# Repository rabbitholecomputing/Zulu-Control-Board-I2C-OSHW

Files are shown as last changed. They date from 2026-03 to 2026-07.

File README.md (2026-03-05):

# Zulu Control Board V1.1 I2C OSHW
This design was originally created to control the ZuluIDE in a 5.25" bracket. It has been relicensed under the OSHW CERN OWL-S V2 see [LICENSE](LICENSE) for the community to spin their own version or produce this design themselves.

The design is created in KiCAD 9.  Gerber, BOM, and position files can be built automatically as a Github action.

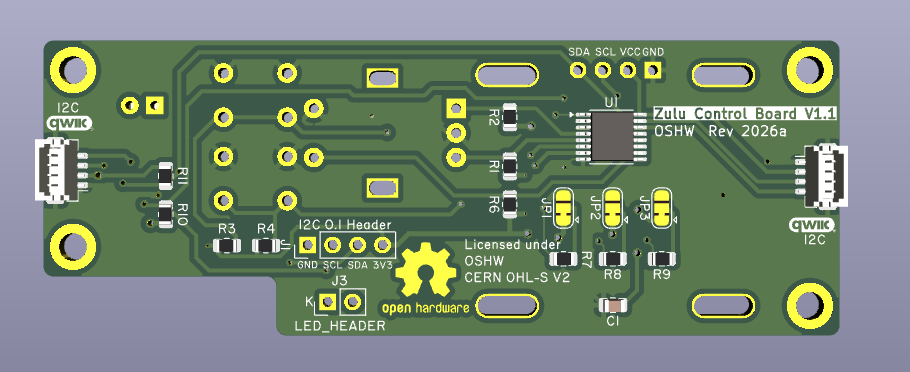
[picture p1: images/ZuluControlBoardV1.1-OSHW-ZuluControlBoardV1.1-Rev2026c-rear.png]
Zulu Control Board front render


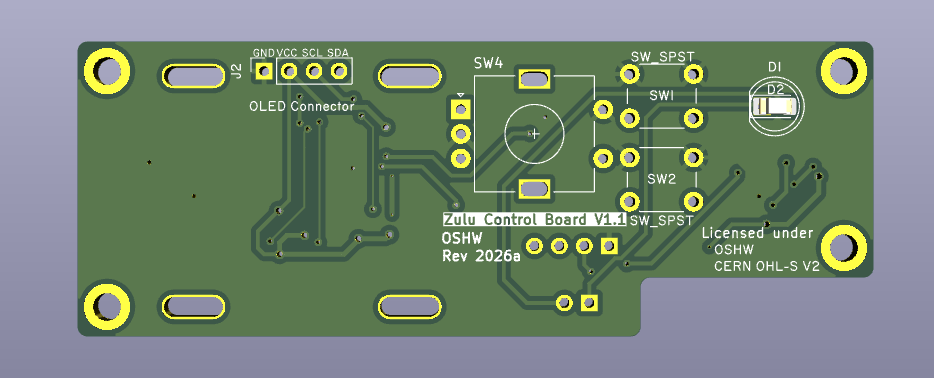
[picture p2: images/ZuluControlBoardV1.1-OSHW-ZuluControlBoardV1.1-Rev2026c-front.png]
Zulu Control Board front render


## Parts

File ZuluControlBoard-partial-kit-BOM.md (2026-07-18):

# i2c Zulu Control board BOM for partially-assembled PCB kit
## (all surface-mount components mounted)

* SW1 & SW2 - P/N MJTP1230BL Any 6x6mm footprint pushbutton tactile switch/pushbuttons should work.
*  J2 - [0.96" OLED module](https://www.digikey.com/en/products/detail/canaduino/26095/16822116), sourceable via Amazon, AliExpres, eBay, etc.
The 0.96" OLED display modules are commodity items, see https://www.amazon.com/dp/B09T6SJBV5. Any 128x64 SSD1306-based OLED display with the correct pinout (GND, VCC, SCL, SCA, _in that order_) should work.

* D1 - This 5mm activity LED is optional. If you choose to install an LED there, make sure it's intended to operate at ~3-3.3 volts DC.
 
* J2 - Optional two-pin LED activity header on the control board, which must be separately connected to the two-pin activity LED header on the ZuluSCSI, as the Qwiic cable does not carry signals for that. 

* SW4, Rotary encoder: Apls Alpine [EC11E152440D](https://tech.alpsalpine.com/e/products/category/encorders/sub/01/series/ec11e/) or [similar Chinese-made "**EC11E**" equivalent](https://www.amazon.com/s?k=rotary+encoder+EC11).

Please note that **non-pushbutton** rotary encoders **are not supported** by the firmware, so be sure to obtain one that has pushbutton/push-on support.

The following Alps Alpine EC11E rotary encoders are pushbutton-equipped models:

* [EC11E15244G1](https://octopart.com/search?specs=0&full_query=EC11E15244G1)
* [EC11E18244AU](https://octopart.com/search?specs=0&full_query=EC11E18244AU)
* [EC11E09244AQ](https://octopart.com/search?specs=0&full_query=EC11E09244AQ)
* [EC11E15244B2](https://octopart.com/search?specs=0&full_query=EC11E15244B2)
* [EC11E18244A5](https://octopart.com/search?specs=0&full_query=EC11E18244A5)

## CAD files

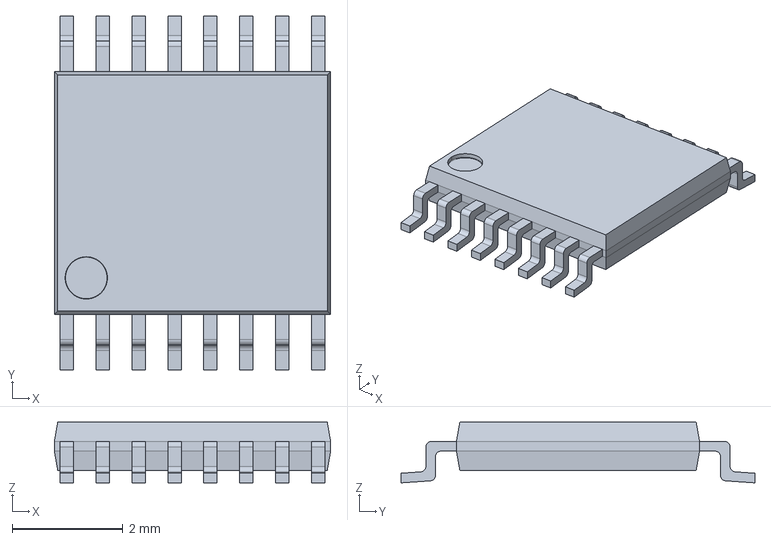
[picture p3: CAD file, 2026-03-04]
PCA9554APW_118/PCA9554APW_118.step
5.00 x 6.41 x 1.10 mm

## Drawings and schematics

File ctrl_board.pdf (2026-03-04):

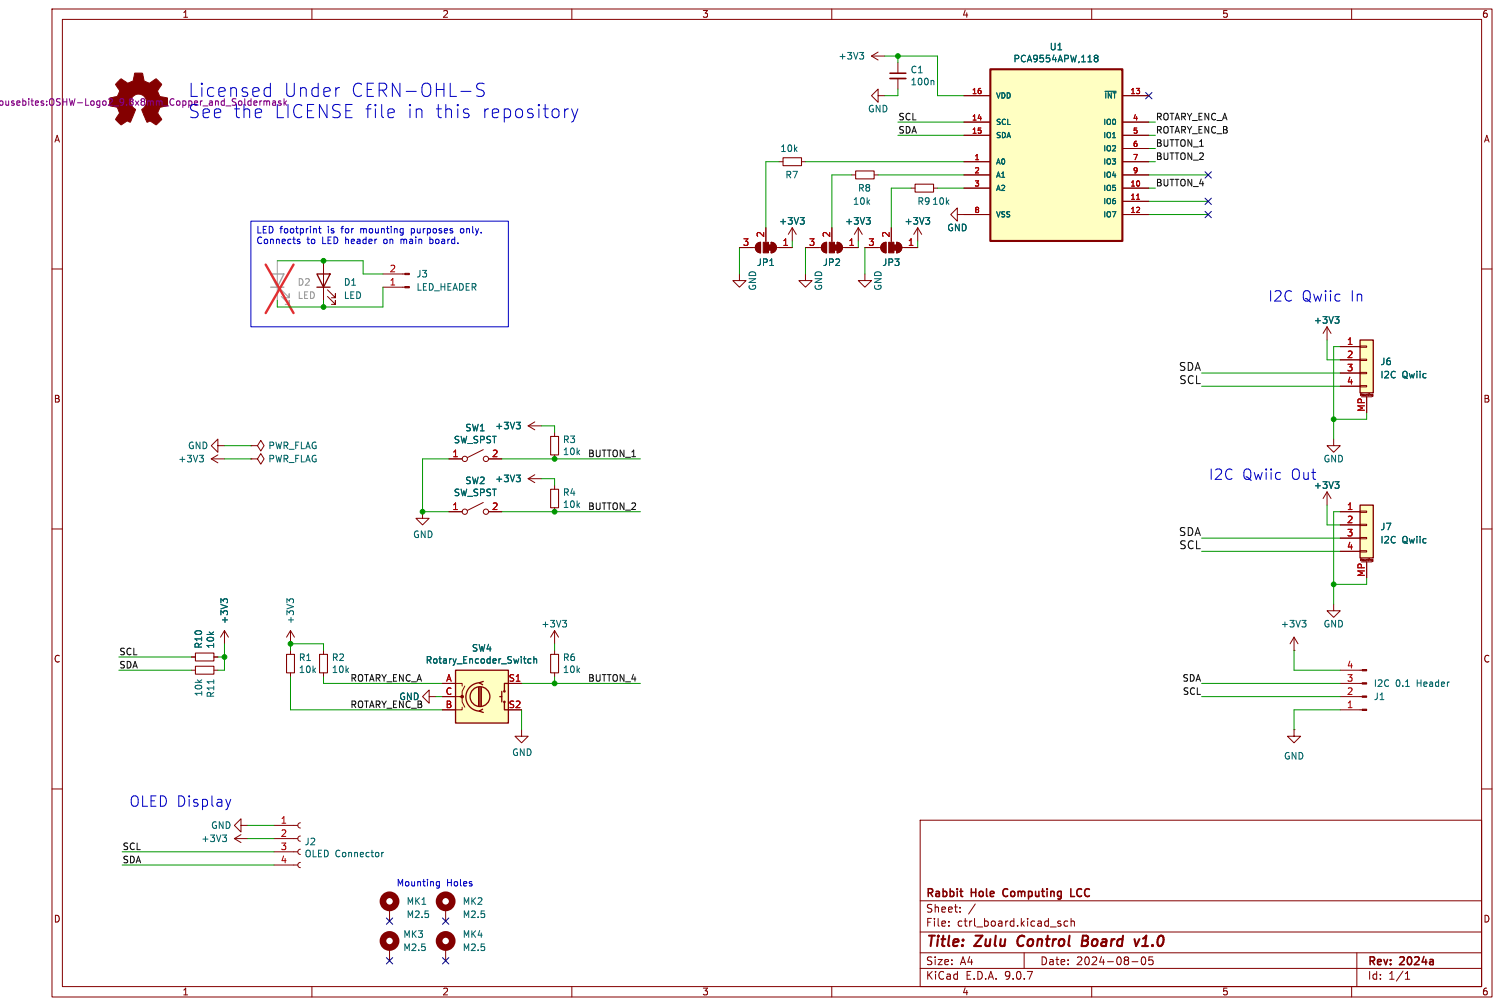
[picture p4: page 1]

See the LICENSE file in this repository

Id: 1/1 Title: Zulu Control Board v1.0

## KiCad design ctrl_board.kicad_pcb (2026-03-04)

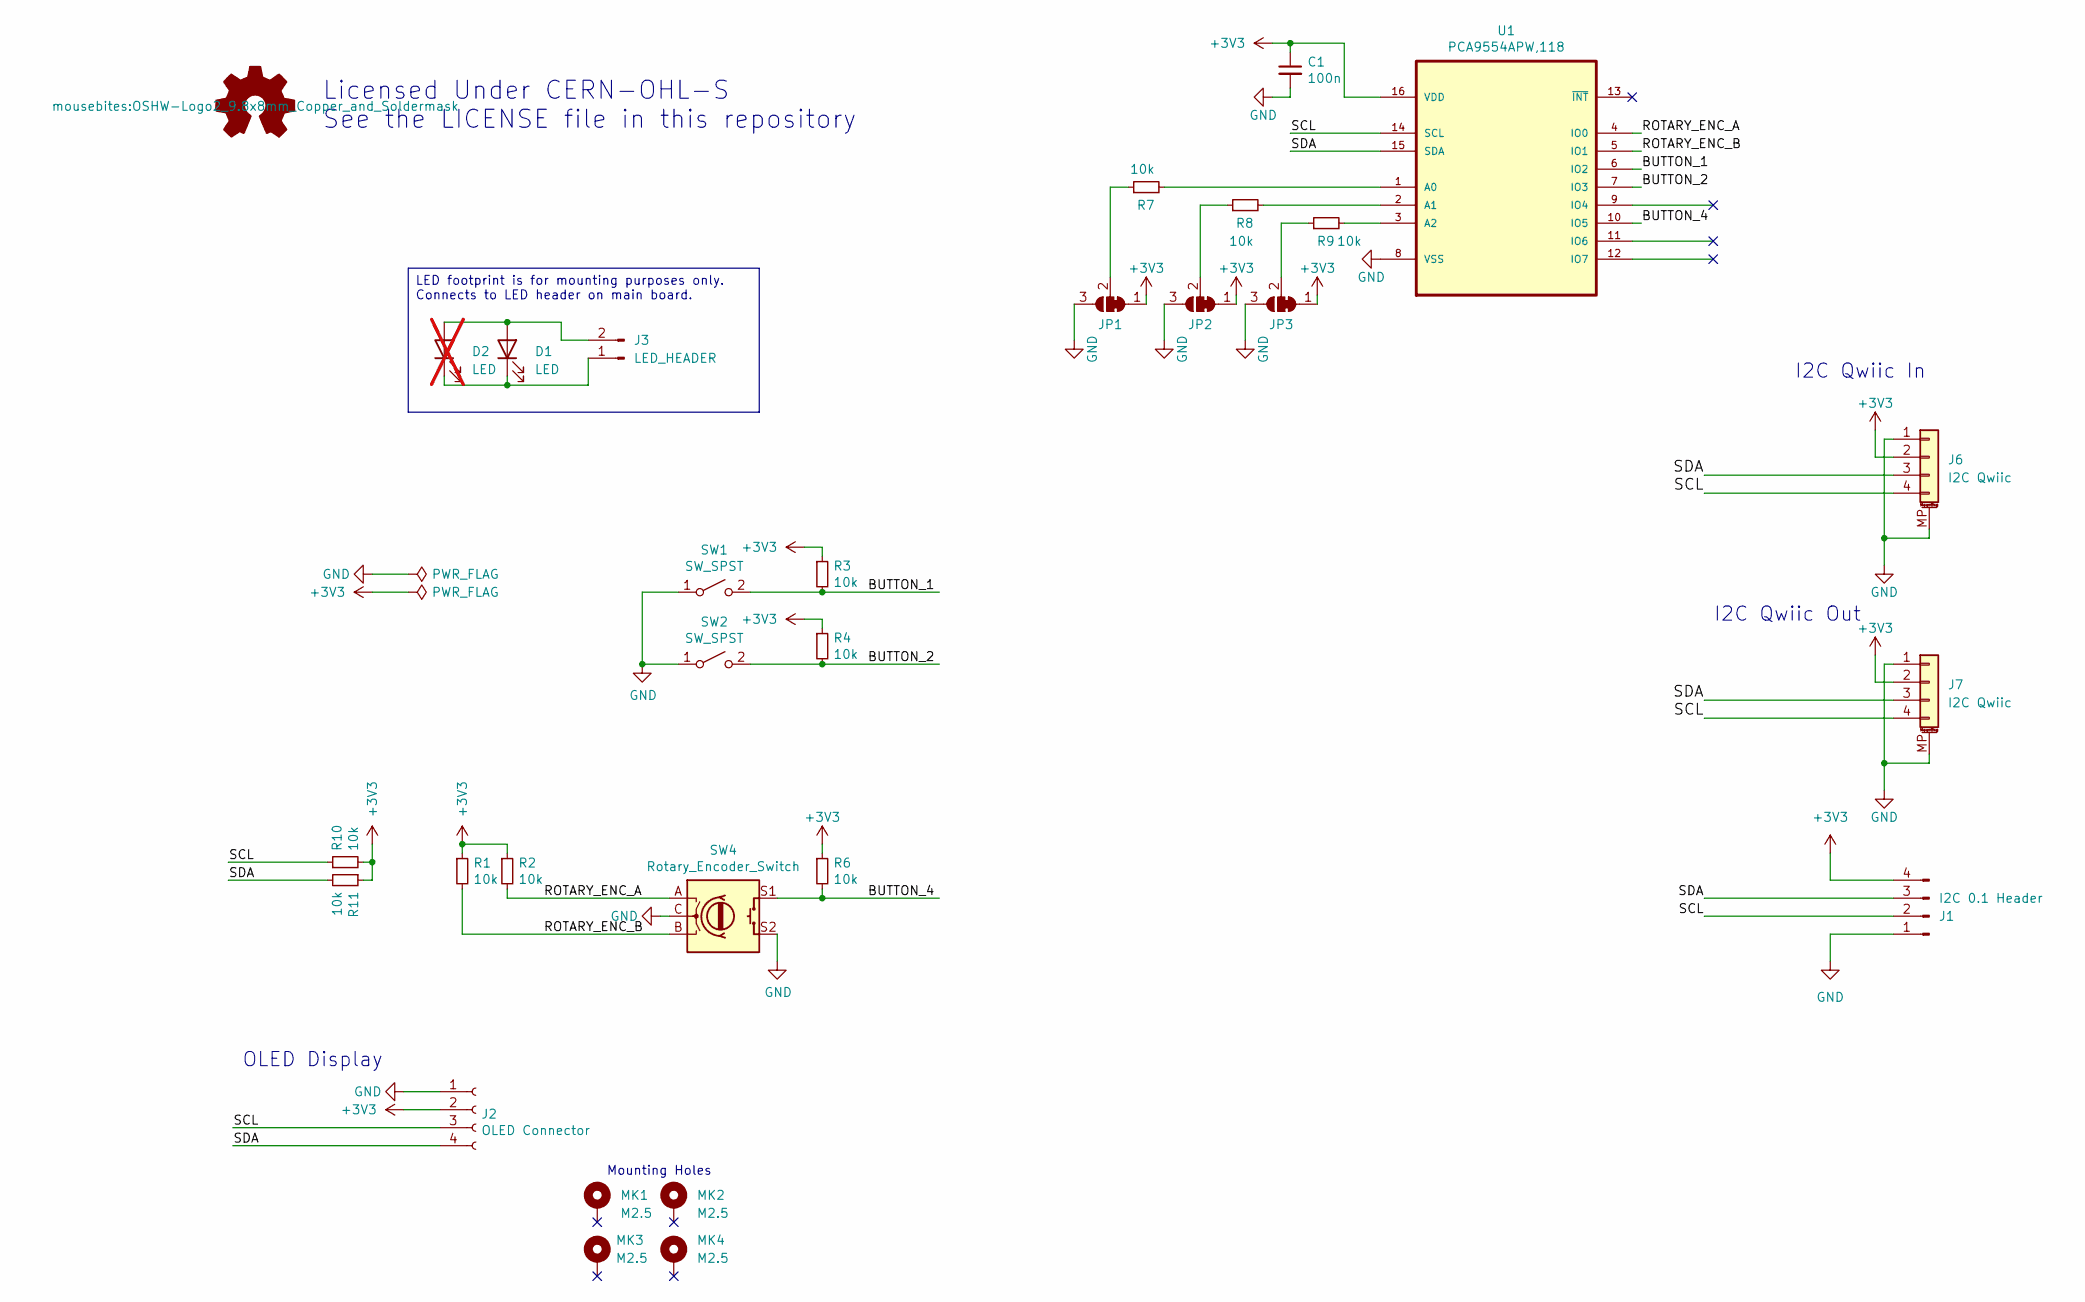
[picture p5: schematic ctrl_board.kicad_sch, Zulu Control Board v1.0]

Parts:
C1: 100n; C_0805_2012Metric; LCSC C49678
D1: LED; LED_D5.0mm
D2: LED; LED_1206_3216Metric_Pad1.42x1.75mm_HandSolder; not fitted
J1: I2C 0.1 Header; PinHeader_1x04_P2.54mm_Vertical
J2: OLED Connector; 0.9_and_1.3_in_OLED_Footprint
J3: LED_HEADER; PinHeader_1x02_P2.54mm_Vertical
J6, J7: I2C Qwiic; CONN4_BM04B-SRSS_JST; LCSC C160390
JP1, JP2, JP3: SolderJumper_3_Bridged12; SolderJumper-3_P1.3mm_Bridged12_RoundedPad1.0x1.5mm
MK1, MK2, MK3, MK4: M2.5; MountingHole_2.8mm_M2.5custom_DIN965_Pad
R1, R2, R3, R4, R6, R7, R8, R9, R10, R11: 10k; R_0805_2012Metric; LCSC C17414
SW1, SW2: SW_SPST; SW_PUSH_6mm_H5mm; LCSC C110153
SW4: Rotary_Encoder_Switch; RotaryEncoder_Bourns_PEC12R-4225F-S0024_H25mm; MPN PEC12R-4225F-S0024; LCSC C5331618
SYM1: Logo_Open_Hardware_Small; OSHW-Logo2_9.8x8mm_Copper_and_Soldermask
U1: PCA9554APW,118; TSSOP-16_4.4x5mm_P0.65mm; MPN PCA9554APW,118; LCSC C86803

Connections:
+3V3: C1.1, J1.4, J2.2, J6.2, J7.2, JP1.1 (A), JP2.1 (A), JP3.1 (A), R1.1, R2.1, R3.1, R4.1, R6.1, R10.2, R11.1, U1.16 (VDD)
/BUTTON_1: R3.2, SW1.2 (B), U1.6 (IO2)
/BUTTON_2: R4.2, SW2.2 (B), U1.7 (IO3)
/BUTTON_4: R6.2, SW4.S1, U1.10 (IO5)
/ROTARY_ENC_A: R2.2, SW4.A, U1.4 (IO0)
/ROTARY_ENC_B: R1.2, SW4.B, U1.5 (IO1)
/SCL: J1.2, J2.3, J6.4, J7.4, R10.1, U1.14 (SCL)
/SDA: J1.3, J2.4, J6.3, J7.3, R11.2, U1.15 (SDA)
GND: C1.2, J1.1, J2.1, J6.1, J6.MP (MountPin), J7.1, J7.MP (MountPin), JP1.3 (B), JP2.3 (B), JP3.3 (B), SW1.1 (A), SW2.1 (A), SW4.C, SW4.S2, U1.8 (VSS)
unnamed: D1.2 (A), D2.2 (A), J3.2
unnamed: D1.1 (K), D2.1 (K), J3.1
unnamed: JP1.2 (C), R7.1
unnamed: JP2.2 (C), R8.1
unnamed: JP3.2 (C), R9.1
unnamed: R7.2, U1.1 (A0)
unnamed: R8.2, U1.2 (A1)
unnamed: R9.2, U1.3 (A2)

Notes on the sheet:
I2C Qwiic In
I2C Qwiic Out
OLED Display
Mounting Holes
Licensed Under CERN-OHL-S See the LICENSE file in this repository
LED footprint is for mounting purposes only. Connects to LED header on main board.

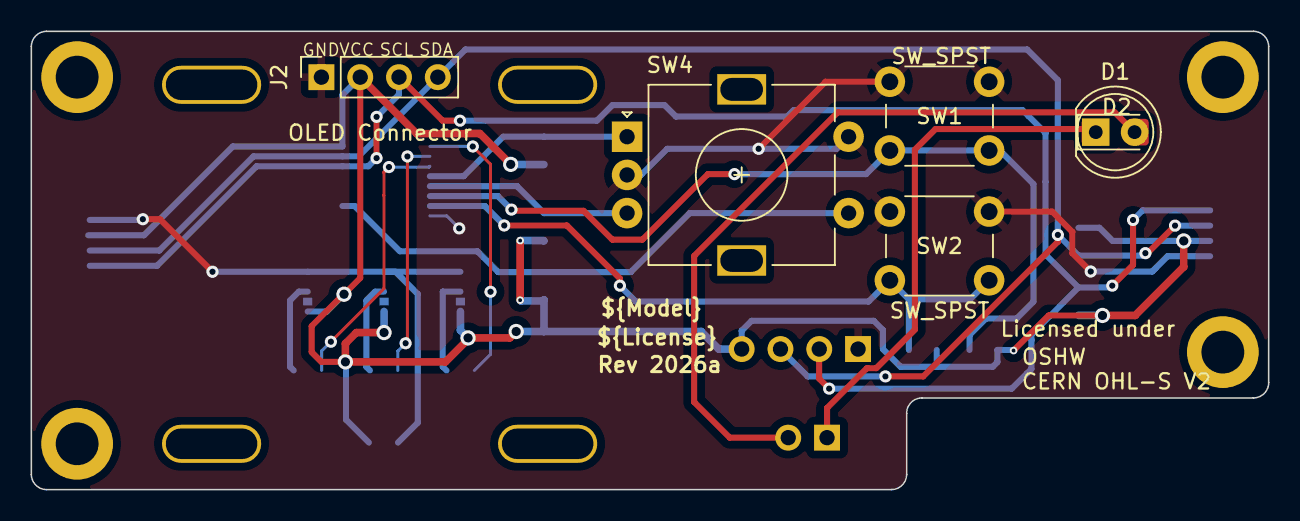
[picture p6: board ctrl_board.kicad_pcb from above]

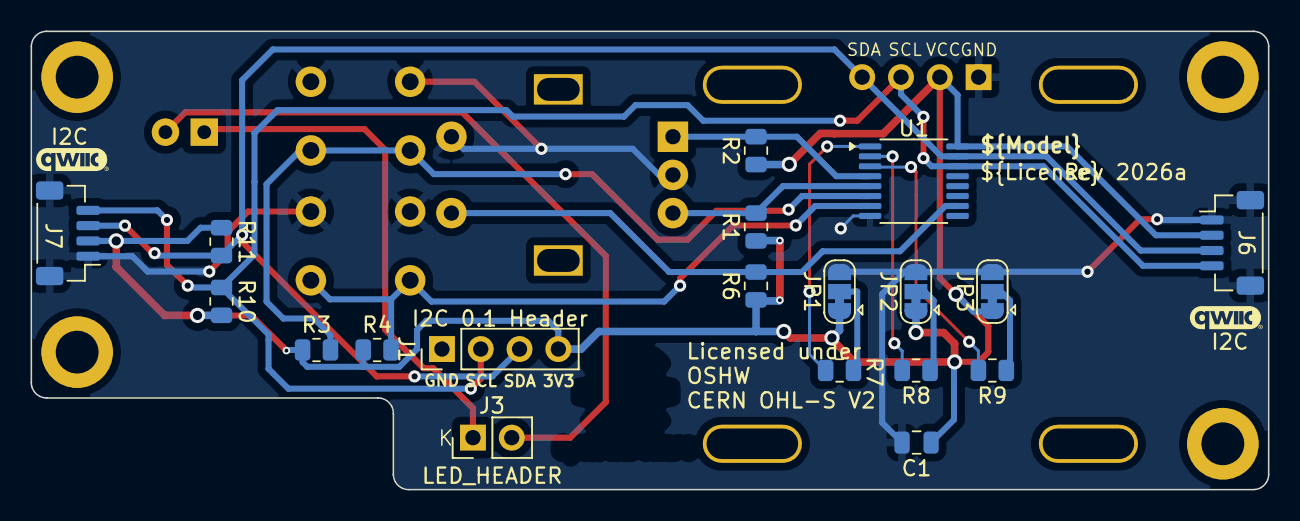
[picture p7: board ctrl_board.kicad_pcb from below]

Board: 2 copper layers, 81.0 x 30.0 mm, 30 parts (20 on the bottom side), 17 nets.

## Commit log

2026-03-05 Add PCB renders of front and back, link from README
2026-07-18 Add through-hole component BOM for Zulu Control board kit
2026-07-18 Revise rotary encoder details and add alternatives
    Updated rotary encoder part number and added links to alternative models.

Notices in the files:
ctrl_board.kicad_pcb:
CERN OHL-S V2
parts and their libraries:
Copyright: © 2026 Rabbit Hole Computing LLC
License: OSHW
